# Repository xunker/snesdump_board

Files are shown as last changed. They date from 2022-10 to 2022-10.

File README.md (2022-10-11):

SNESDump Board
==============

A board for use with [https://github.com/cthill/SNESDump].

It is designed completely with through-hole components because that's what most people have lying
around.

The routing is _ugly_ because I wanted the board to be compatible with the original code without any
changes.

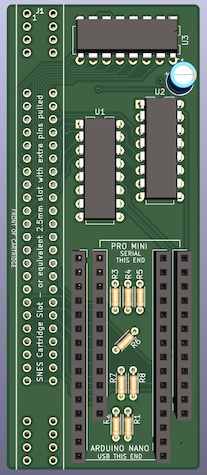
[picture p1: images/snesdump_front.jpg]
Picture of front of board
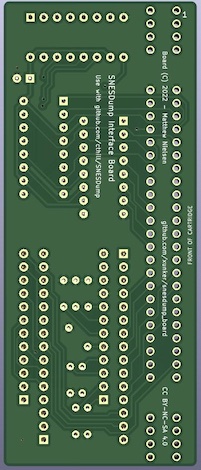
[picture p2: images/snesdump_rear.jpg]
Picture of rear of board
 

## Bill of Materials

* Cartridge Slot (1)
  - The cartridge slot can be either
    * A scavenged slot from a real SNES or Super-Famicom
    * A compatible 2.5mm 70-pin slot can be used with the appropriate pins yanked out
      - This slot *MUST* be 2.5mm pitch (so-called "metric spacing") and not the more common 2.54mm
    pitch (0.1 inches)

* Resistors (8)
  - Any 10K resistors will work as long as they can physically fit

* Shift Registers (3)
  - Any through-hole 74HC595N or compatible will work
  - Use of DIP sockets is recommended to make troubleshooting easier

* Arduino/Microcontroller
  - You can use either an Arduino Nano or Arduino Pro Micro (or clones thereof) in the indicated
    footprint
  - For obvious reasons you can't use both at the same time
  - It is **highly** recommended to mount the microcontroller on headers so it can be removed later

* Decoupling Capacitor (optional)
  - an electrolytic capacitor with a rating of at least 6.3v and a value from 0.1uF to 10uF will
    improve the general stability of the reader

## Licenses

SNES Slot Footprint ([SNES-CONN-EXP.kicad_mod](https://github.com/db-electronics/kicadlib)) is
distributed under the terms of CERN OHL v.1.2.

Arduino Pro Mini symbol and footprint (used as reference, not in final board output) is from
[SnapEDA](https://www.snapeda.com/parts/Arduino%20Pro%20Mini/Arduino/view-part/) and distributed
under [their license](footprints/SnapEDA+License.txt).

Unless otherwise specified, all other content herein is (C) 2022 Matthew Nielsen and is distributed
under the terms of [CC BY-NC-SA 4.0](https://creativecommons.org/licenses/by-nc-sa/4.0/).

### Sale of this board is NOT ALLOWED

I'm annoyed that I need to write this, but I do:

> ❗ ANY SALE OF THIS DESIGN IS STRICTLY PROHIBITED UNLESS AUTHORIZED IN WRITING BY RIGHTS HOLDER
>
> You **ARE ALLOWED** to make copies of this board for your __personal__ use, __give__ them to your
> friends, hand them out __for free__ to strangers on the street, or any other purpose so long as
> *you neither ask for nor receive payment* of any kind.
>
> You **ARE NOT ALLOWED** to make copies and sell them. Period. Whether you sell them for a profit
> or for a loss, it is not allowed. Whether you charge "for materials", "for time/labour", "for
> shipping and handling", it is not allowed.

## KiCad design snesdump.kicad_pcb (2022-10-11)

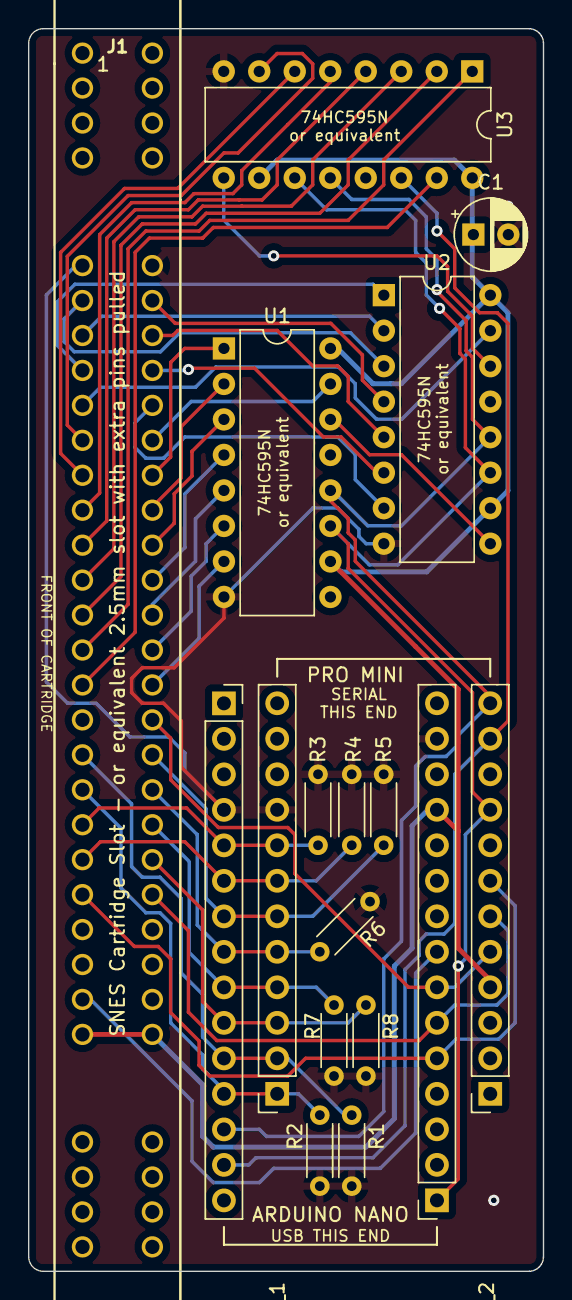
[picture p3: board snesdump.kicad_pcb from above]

Board: 2 copper layers, 36.8 x 88.9 mm, 17 parts (0 on the bottom side), 43 nets.

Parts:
C1: 0.47uF; CP_Radial_D5.0mm_P2.50mm
J1: CARTRIDGE_SLOT; SNES-CONN-EXP
NANO_1, NANO_2: Conn_01x15_Male; PinSocket_1x15_P2.54mm_Vertical
PRO_MINI_1, PRO_MINI_2: Conn_01x12_Male; PinSocket_1x12_P2.54mm_Vertical
R1, R2, R3, R4, R5, R6, R7, R8: 10K; R_Axial_DIN0204_L3.6mm_D1.6mm_P5.08mm_Horizontal
U1, U2, U3: 74HC595; DIP-16_W7.62mm

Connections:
+5V: C1.1, J1.27, J1.58, NANO_2.12, PRO_MINI_2.4, U1.10 (~SRCLR), U1.16 (VCC), U2.10 (~SRCLR), U2.16 (VCC), U3.10 (~SRCLR), U3.16 (VCC)
A00: J1.17, U3.15 (QA)
A01: J1.16, U3.1 (QB)
A02: J1.15, U3.2 (QC)
A03: J1.14, U3.3 (QD)
A04: J1.13, U3.4 (QE)
A05: J1.12, U3.5 (QF)
A06: J1.11, U3.6 (QG)
A07: J1.10, U3.7 (QH)
A08: J1.9, U2.15 (QA)
A09: J1.8, U2.1 (QB)
A10: J1.7, U2.2 (QC)
A11: J1.6, U2.3 (QD)
A12: J1.37, U2.4 (QE)
A13: J1.38, U2.5 (QF)
A14: J1.39, U2.6 (QG)
A15: J1.40, U2.7 (QH)
BA0: J1.41, U1.15 (QA)
BA1: J1.42, U1.1 (QB)
BA2: J1.43, U1.2 (QC)
BA3: J1.44, U1.3 (QD)
BA4: J1.45, U1.4 (QE)
BA5: J1.46, U1.5 (QF)
BA6: J1.47, U1.6 (QG)
BA7: J1.48, U1.7 (QH)
D0: J1.19, NANO_1.11, PRO_MINI_1.2, R1.1
D1: J1.20, NANO_1.12, PRO_MINI_1.1, R2.1
D2: J1.21, NANO_1.5, PRO_MINI_1.8, R3.1
D3: J1.22, NANO_1.6, PRO_MINI_1.7, R4.1
D4: J1.50, NANO_1.7, PRO_MINI_1.6, R5.1
D5: J1.51, NANO_1.8, PRO_MINI_1.5, R6.1
D6: J1.52, NANO_1.9, PRO_MINI_1.4, R7.1
D7: J1.53, NANO_1.10, PRO_MINI_1.3, R8.1
GND: C1.2, J1.5, J1.36, NANO_1.4, NANO_2.14, PRO_MINI_1.9, R1.2, R2.2, R3.2, R4.2, R5.2, R6.2, R7.2, R8.2, U1.8 (GND), U2.8 (GND), U3.8 (GND)
RCK: NANO_1.13, PRO_MINI_2.12, U1.12 (RCLK), U2.12 (RCLK), U3.12 (RCLK)
SCK: NANO_2.1, PRO_MINI_2.9, U1.11 (SRCLK), U2.11 (SRCLK), U3.11 (SRCLK)
SER_1_2: U1.14 (SER), U2.9 (QH')
SER_2_3: U2.14 (SER), U3.9 (QH')
SER_3_D11: NANO_1.14, PRO_MINI_2.11, U3.14 (SER)
/CS: J1.49, NANO_2.7, PRO_MINI_2.5
/RD: J1.23, NANO_2.5, PRO_MINI_2.7
/RESET: J1.26, NANO_2.8
/WR: J1.54, NANO_2.6, PRO_MINI_2.6

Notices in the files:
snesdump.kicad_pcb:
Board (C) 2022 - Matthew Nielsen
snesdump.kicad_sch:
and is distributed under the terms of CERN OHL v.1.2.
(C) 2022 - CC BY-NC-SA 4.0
